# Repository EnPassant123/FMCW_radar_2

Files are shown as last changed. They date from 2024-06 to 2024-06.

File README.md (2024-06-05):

**FMCW Radar Project**

Contains design files, Verilog code for FPGA, and C code for computer.

Can be easily modified to act as a data streaming board (just disable sweep)

Code is still very buggy and does not pass timing. Use at your own risk!

Untested PCB changes: Added LDO to cut down on power supply noise (from USB) more.

The C code is based on libftdi1, and some changes need to be made to ftdi_stream.c

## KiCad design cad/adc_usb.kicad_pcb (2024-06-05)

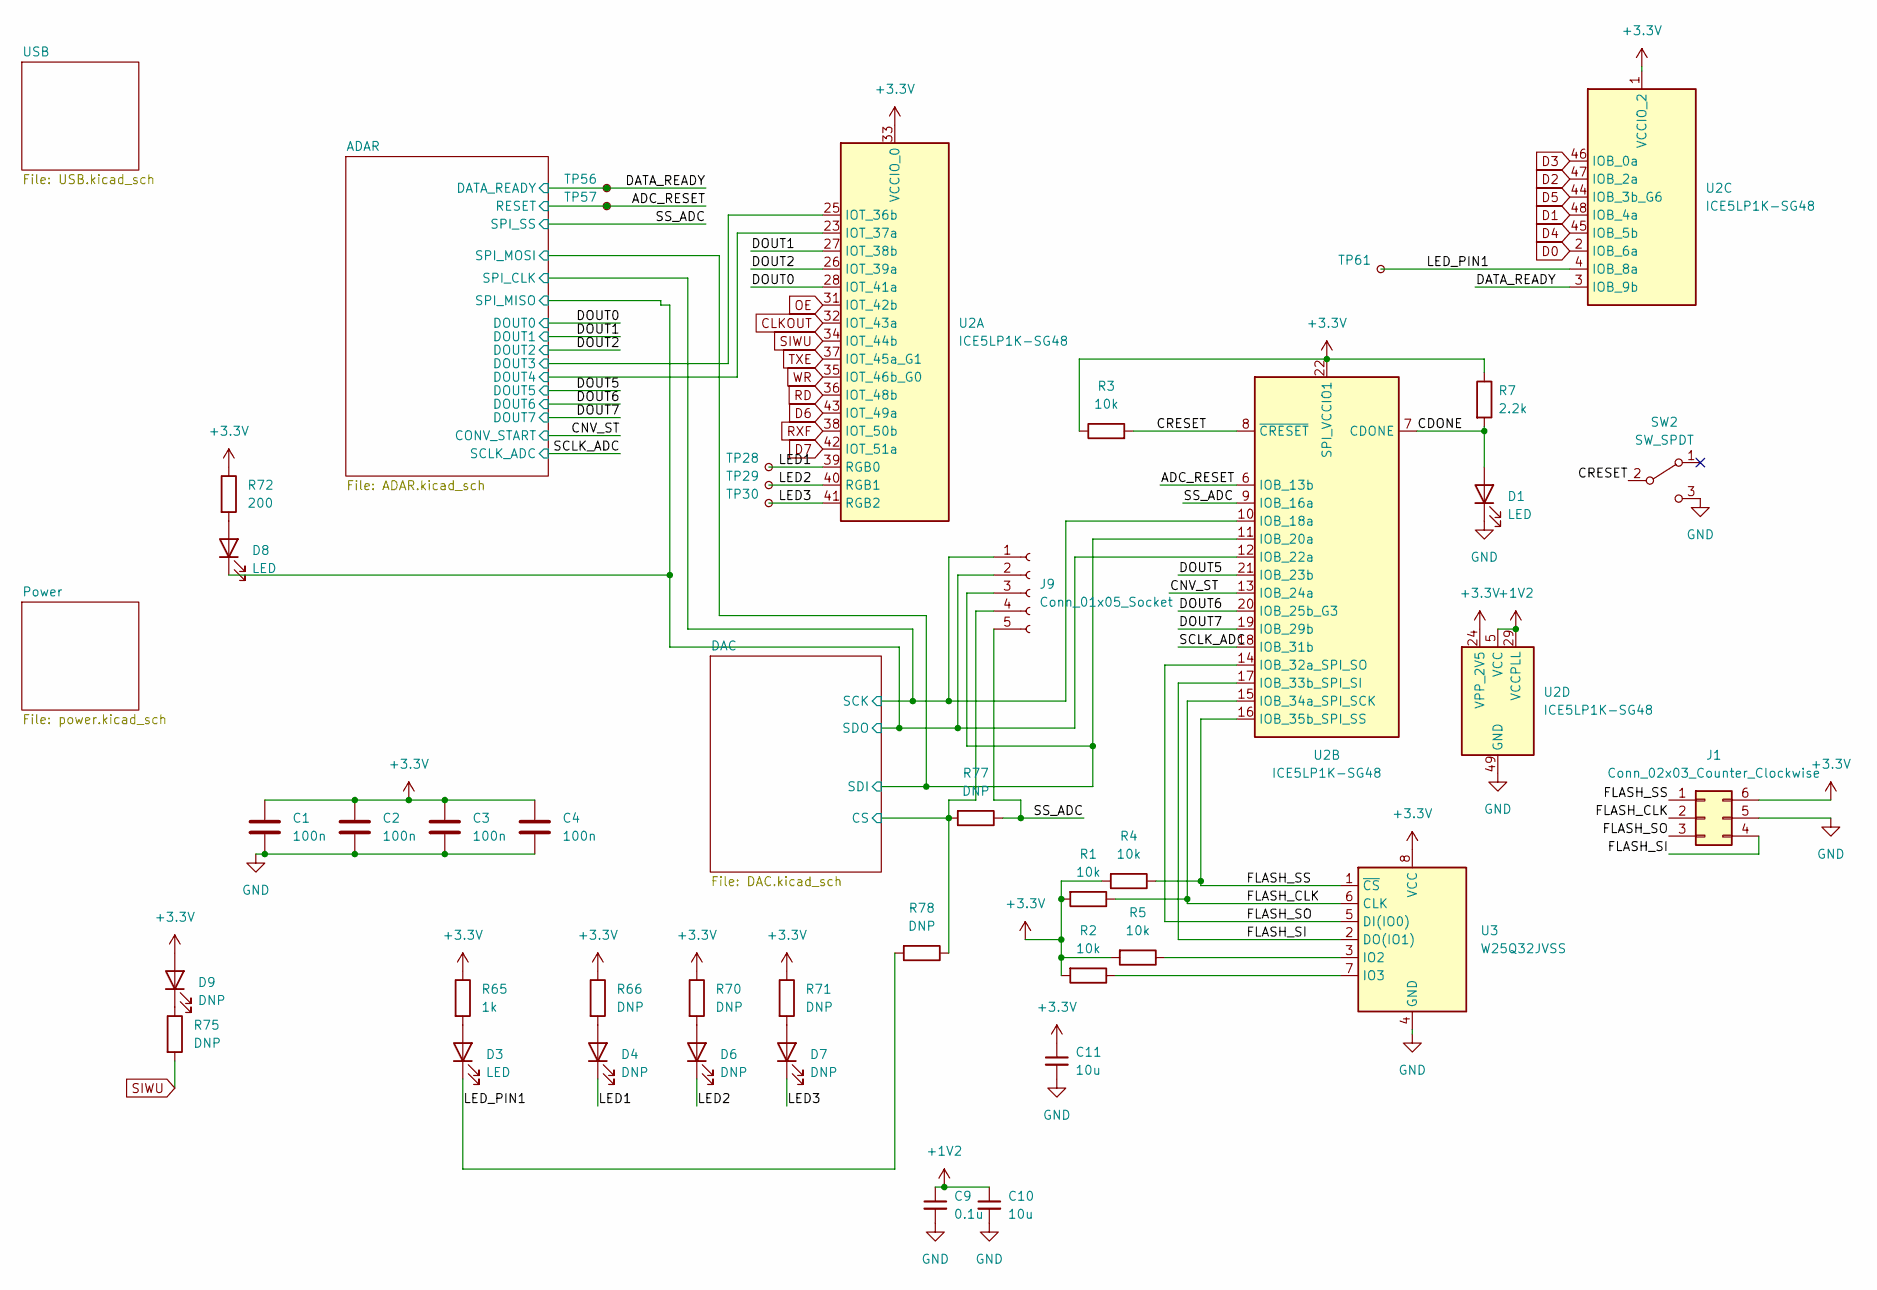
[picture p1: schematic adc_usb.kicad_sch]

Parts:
C1, C2, C3, C4: 100n; C_0603_1608Metric
C9: 0.1u; C_0603_1608Metric
C10, C11: 10u; C_0603_1608Metric
D1, D3, D8: LED; LED_1206_3216Metric
D4, D6, D7, D9: DNP; LED_1206_3216Metric
J1: Conn_02x03_Counter_Clockwise; PinSocket_2x03_P2.54mm_Vertical
J9: Conn_01x05_Socket; PinSocket_1x05_P2.54mm_Vertical
R1, R2, R3, R4, R5: 10k; R_0603_1608Metric
R7: 2.2k; R_0603_1608Metric
R65: 1k; R_0603_1608Metric
R66, R70, R71, R75, R77, R78: DNP; R_0603_1608Metric
R72: 200; R_0603_1608Metric
SW2: SW_SPDT; PinHeader_1x03_P2.54mm_Vertical
TP28, TP29, TP30, TP56, TP57, TP61: TestPoint_Small; TestPoint_Pad_1.0x1.0mm
U2: ICE5LP1K-SG48; QFN-48-1EP_7x7mm_P0.5mm_EP5.6x5.6mm
U3: W25Q32JVSS; SOIC-8_5.23x5.23mm_P1.27mm

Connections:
+1V2: C9.1, C10.1, U2.5 (VCC), U2.29 (VCCPLL), U2.30 (VCC); also elsewhere on the board
+3.3V: C1.1, C2.1, C3.1, C4.1, C11.1, D9.2 (A), J1.6, R1.2, R2.2, R3.1, R4.2, R5.2, R7.1, R65.1, R66.1, R70.1, R71.1, R72.1, U2.1 (VCCIO_2), U2.22 (SPI_VCCIO1), U2.24 (VPP_2V5), U2.33 (VCCIO_0), U3.8 (VCC); also elsewhere on the board
/ADAR/DOUT3: U2.25 (IOT_36b); also elsewhere on the board
/ADAR/DOUT4: U2.23 (IOT_37a); also elsewhere on the board
/ADAR/SPI_CLK: J9.1, U2.10 (IOB_18a); also elsewhere on the board
/ADAR/SPI_MISO: D8.1 (K), J9.2, U2.12 (IOB_22a); also elsewhere on the board
/ADAR/SPI_MOSI: J9.3, U2.11 (IOB_20a); also elsewhere on the board
/ADC_RESET: TP57.1, U2.6 (IOB_13b); also elsewhere on the board
/CDONE: D1.2 (A), R7.2, U2.7 (CDONE)
/CNV_ST: U2.13 (IOB_24a); also elsewhere on the board
/CRESET: R3.2, SW2.2 (B), U2.8 (~CRESET)
/DAC/CS: J9.4, R77.2, R78.1; also elsewhere on the board
/DATA_READY: TP56.1, U2.3 (IOB_9b); also elsewhere on the board
/DOUT0: U2.28 (IOT_41a); also elsewhere on the board
/DOUT1: U2.27 (IOT_38b); also elsewhere on the board
/DOUT2: U2.26 (IOT_39a); also elsewhere on the board
/DOUT5: U2.21 (IOB_23b); also elsewhere on the board
/DOUT6: U2.20 (IOB_25b_G3); also elsewhere on the board
/DOUT7: U2.19 (IOB_29b); also elsewhere on the board
/FLASH_CLK: J1.2, R1.1, U2.15 (IOB_34a_SPI_SCK), U3.6 (CLK)
/FLASH_SI: J1.4, U2.17 (IOB_33b_SPI_SI), U3.2 (DO(IO1))
/FLASH_SO: J1.3, U2.14 (IOB_32a_SPI_SO), U3.5 (DI(IO0))
/FLASH_SS: J1.1, R4.1, U2.16 (IOB_35b_SPI_SS), U3.1 (~CS)
/LED1: D4.1 (K), TP28.1, U2.39 (RGB0)
/LED2: D6.1 (K), TP29.1, U2.40 (RGB1)
/LED3: D7.1 (K), TP30.1, U2.41 (RGB2)
/LED_PIN1: D3.1 (K), R78.2, TP61.1, U2.4 (IOB_8a)
/SCLK_ADC: U2.18 (IOB_31b); also elsewhere on the board
/SS_ADC: J9.5, R77.1, U2.9 (IOB_16a); also elsewhere on the board
CLKOUT: U2.32 (IOT_43a); also elsewhere on the board
D0: U2.2 (IOB_6a); also elsewhere on the board
D1: U2.48 (IOB_4a); also elsewhere on the board
D2: U2.47 (IOB_2a); also elsewhere on the board
D3: U2.46 (IOB_0a); also elsewhere on the board
D4: U2.45 (IOB_5b); also elsewhere on the board
D5: U2.44 (IOB_3b_G6); also elsewhere on the board
D6: U2.43 (IOT_49a); also elsewhere on the board
D7: U2.42 (IOT_51a); also elsewhere on the board
GND: C1.2, C2.2, C3.2, C4.2, C9.2, C10.2, C11.2, D1.1 (K), J1.5, SW2.3 (C), U2.49 (GND), U3.4 (GND); also elsewhere on the board
unnamed: D3.2 (A), R65.2
unnamed: D4.2 (A), R66.2
unnamed: D6.2 (A), R70.2
unnamed: D7.2 (A), R71.2
unnamed: D8.2 (A), R72.2
unnamed: D9.1 (K), R75.1
unnamed: R5.1, U3.3 (IO2)
unnamed: R2.1, U3.7 (IO3)
OE: U2.31 (IOT_42b); also elsewhere on the board
RD: U2.36 (IOT_48b); also elsewhere on the board
RXF: U2.38 (IOT_50b); also elsewhere on the board
SIWU: R75.2, U2.34 (IOT_44b); also elsewhere on the board
TXE: U2.37 (IOT_45a_G1); also elsewhere on the board
WR: U2.35 (IOT_46b_G0); also elsewhere on the board

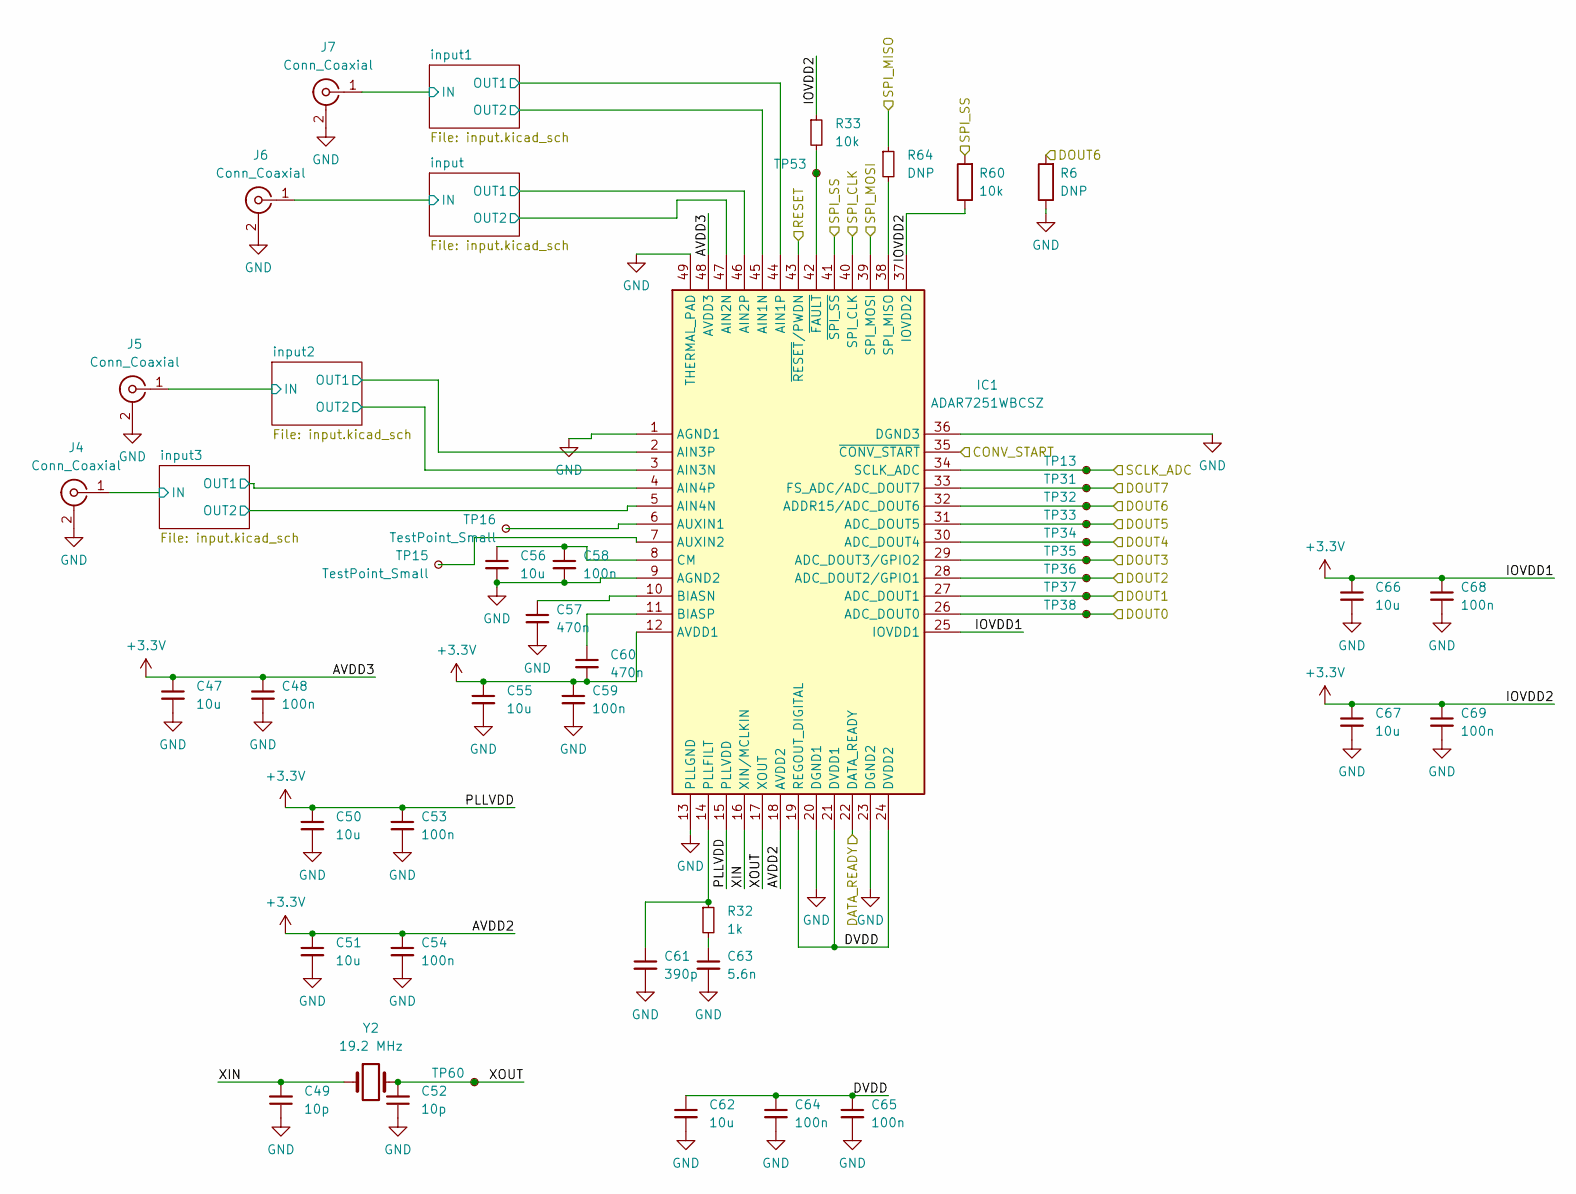
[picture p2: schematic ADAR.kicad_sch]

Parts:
C47, C50, C51, C55, C56, C62, C66, C67: 10u; C_0603_1608Metric
C48, C53, C54, C58, C59, C64, C65, C68, C69: 100n; C_0603_1608Metric
C49, C52: 10p; C_0603_1608Metric
C57, C60: 470n; C_0603_1608Metric
C61: 390p; C_0603_1608Metric
C63: 5.6n; C_0603_1608Metric
IC1: ADAR7251WBCSZ; LFCSP-48-1EP_7x7mm_P0.5mm_EP4.1x4.1mm; Manufacturer_Part_Number ADAR7251WBCSZ; Mouser Part Number 584-ADAR7251WBCSZ
J4, J5, J6, J7: Conn_Coaxial; SMA_Samtec_SMA-J-P-X-ST-EM1_EdgeMount
R6, R64: DNP; R_0603_1608Metric
R32: 1k; R_0603_1608Metric
R33, R60: 10k; R_0603_1608Metric
TP13, TP31, TP32, TP33, TP34, TP35, TP36, TP37, TP38, TP53: TestPoint_Small; TestPoint_Pad_1.0x1.0mm
TP15, TP16, TP60: TestPoint_Small; TestPoint_Pad_2.0x2.0mm
Y2: 19.2 MHz; Crystal_SMD_3225-4Pin_3.2x2.5mm

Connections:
+3.3V: C47.1, C48.1, C50.1, C51.1, C53.1, C54.1, C55.1, C59.1, C60.2, C66.1, C67.1, C68.1, C69.1, IC1.12 (AVDD1), IC1.15 (PLLVDD), IC1.18 (AVDD2), IC1.25 (IOVDD1), IC1.37 (IOVDD2), IC1.48 (AVDD3), R33.1, R60.1; also elsewhere on the board
/ADAR/DOUT3: IC1.29 (ADC_DOUT3/GPIO2), TP35.1; also elsewhere on the board
/ADAR/DOUT4: IC1.30 (ADC_DOUT4), TP34.1; also elsewhere on the board
/ADAR/DVDD: C62.1, C64.1, C65.1, IC1.19 (REGOUT_DIGITAL), IC1.21 (DVDD1), IC1.24 (DVDD2)
/ADAR/SPI_CLK: IC1.40 (SPI_CLK); also elsewhere on the board
/ADAR/SPI_MISO: R64.1; also elsewhere on the board
/ADAR/SPI_MOSI: IC1.39 (SPI_MOSI); also elsewhere on the board
/ADAR/XIN: C49.2, IC1.16 (XIN/MCLKIN), Y2.1
/ADAR/XOUT: C52.2, IC1.17 (XOUT), TP60.1, Y2.2
/ADAR/input1/OUT1: IC1.44 (AIN1P); also elsewhere on the board
/ADAR/input1/OUT2: IC1.45 (AIN1N); also elsewhere on the board
/ADAR/input2/IN: J5.1 (In); also elsewhere on the board
/ADAR/input2/OUT1: IC1.2 (AIN3P); also elsewhere on the board
/ADAR/input2/OUT2: IC1.3 (AIN3N); also elsewhere on the board
/ADAR/input3/OUT1: IC1.4 (AIN4P); also elsewhere on the board
/ADAR/input3/OUT2: IC1.5 (AIN4N); also elsewhere on the board
/ADAR/input/OUT1: IC1.46 (AIN2P); also elsewhere on the board
/ADAR/input/OUT2: IC1.47 (AIN2N); also elsewhere on the board
/ADC_RESET: IC1.43 (~RESET/PWDN); also elsewhere on the board
/CNV_ST: IC1.35 (~CONV_START); also elsewhere on the board
/DATA_READY: IC1.22 (DATA_READY); also elsewhere on the board
/DOUT0: IC1.26 (ADC_DOUT0), TP38.1; also elsewhere on the board
/DOUT1: IC1.27 (ADC_DOUT1), TP37.1; also elsewhere on the board
/DOUT2: IC1.28 (ADC_DOUT2/GPIO1), TP36.1; also elsewhere on the board
/DOUT5: IC1.31 (ADC_DOUT5), TP33.1; also elsewhere on the board
/DOUT6: IC1.32 (ADDR15/ADC_DOUT6), R6.2, TP32.1; also elsewhere on the board
/DOUT7: IC1.33 (FS_ADC/ADC_DOUT7), TP31.1; also elsewhere on the board
/SCLK_ADC: IC1.34 (SCLK_ADC), TP13.1; also elsewhere on the board
/SS_ADC: IC1.41 (~SPI_SS), R60.2; also elsewhere on the board
GND: C47.2, C48.2, C49.1, C50.2, C51.2, C52.1, C53.2, C54.2, C55.2, C56.2, C57.2, C58.2, C59.2, C61.2, C62.2, C63.2, C64.2, C65.2, C66.2, C67.2, C68.2, C69.2, IC1.1 (AGND1), IC1.9 (AGND2), IC1.13 (PLLGND), IC1.20 (DGND1), IC1.23 (DGND2), IC1.36 (DGND3), IC1.49 (THERMAL_PAD), J4.2 (Ext), J5.2 (Ext), J6.2 (Ext), J7.2 (Ext), R6.1; also elsewhere on the board
unnamed: C63.1, R32.2
unnamed: IC1.6 (AUXIN1), TP16.1
unnamed: IC1.7 (AUXIN2), TP15.1
unnamed: C57.1, IC1.10 (BIASN)
unnamed: C60.1, IC1.11 (BIASP)
unnamed: C56.1, C58.1, IC1.8 (CM)
unnamed: C61.1, IC1.14 (PLLFILT), R32.1
unnamed: IC1.38 (SPI_MISO), R64.2
unnamed: IC1.42 (~FAULT), R33.2, TP53.1

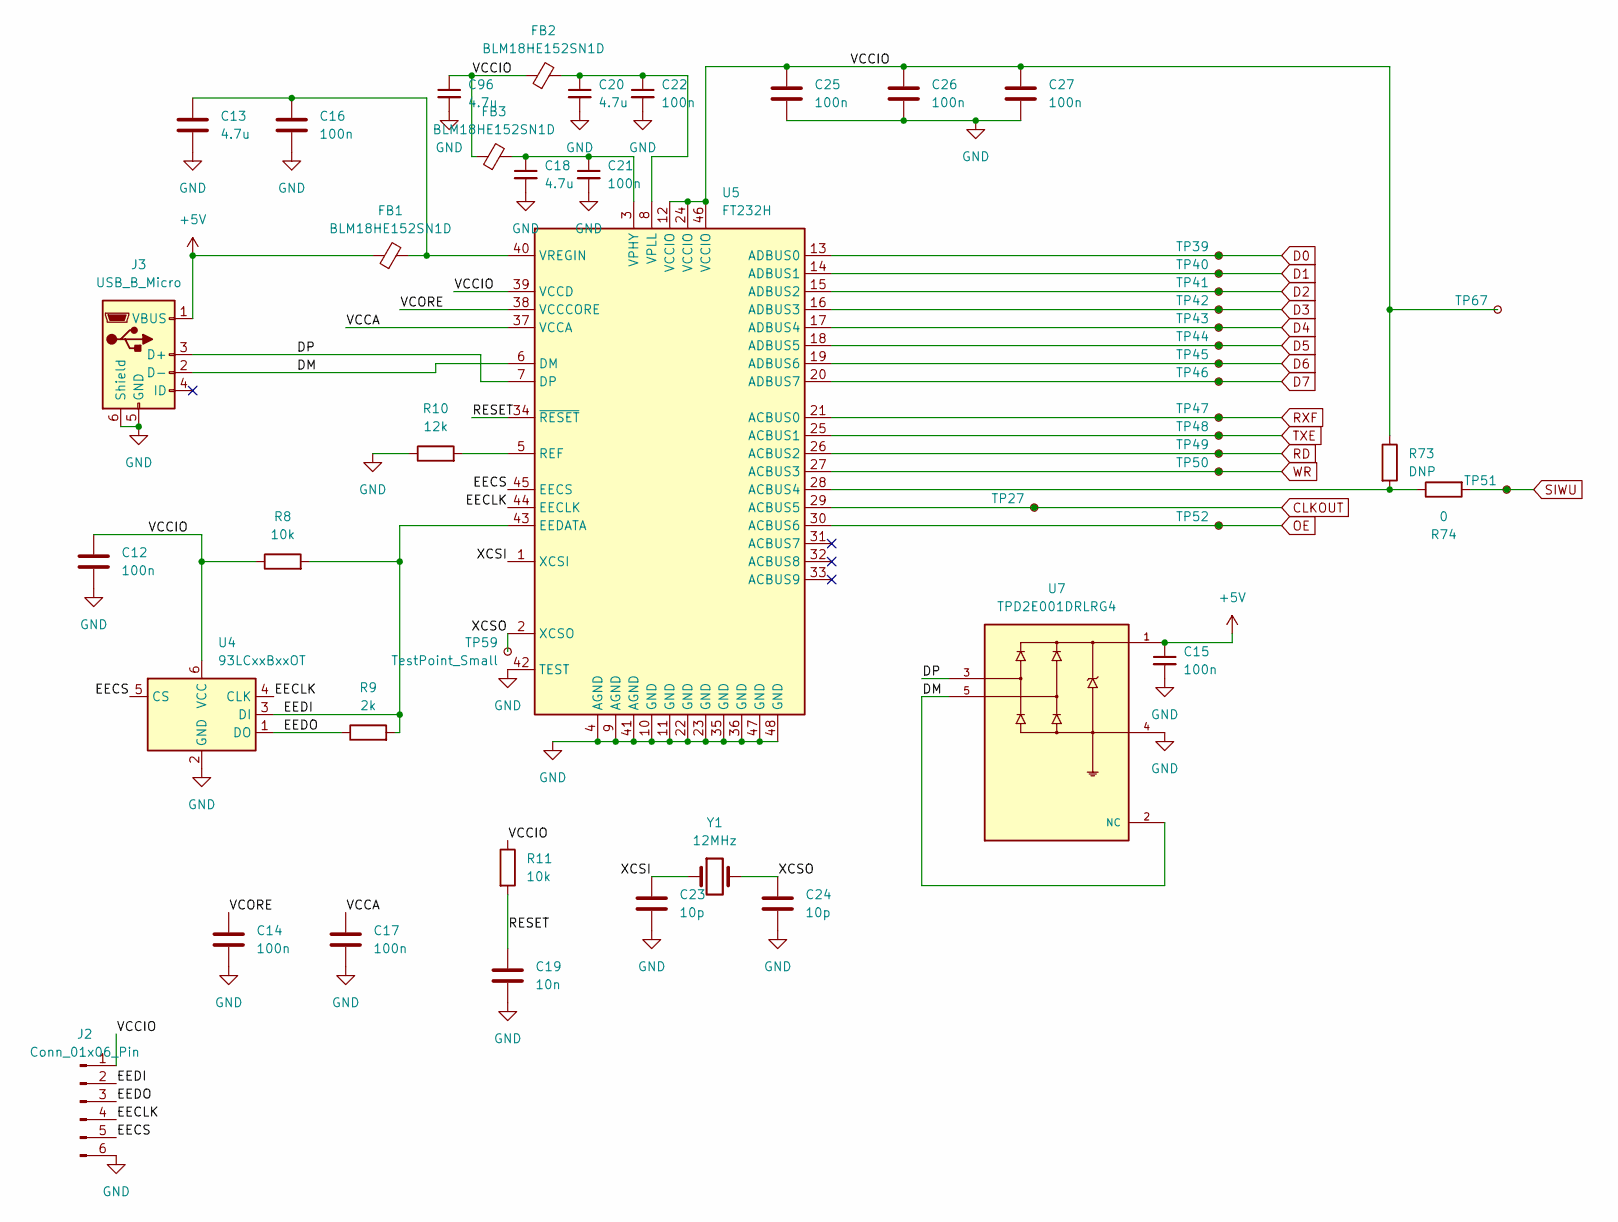
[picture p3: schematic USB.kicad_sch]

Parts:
C12, C14, C15, C16, C17, C21, C22, C25, C26, C27: 100n; C_0603_1608Metric
C13, C18, C20, C96: 4.7u; C_0603_1608Metric
C19: 10n; C_0603_1608Metric
C23, C24: 10p; C_0603_1608Metric
FB1, FB2, FB3: BLM18HE152SN1D; L_0603_1608Metric
J2: Conn_01x06_Pin; PinSocket_1x06_P2.54mm_Vertical
J3: USB_B_Micro; USB_Micro-B_Amphenol_10118193-0001LF_Horizontal
R8, R11: 10k; R_0603_1608Metric
R9: 2k; R_0603_1608Metric
R10: 12k; R_0603_1608Metric
R73: DNP; R_0603_1608Metric
R74: 0; R_0603_1608Metric
TP27, TP39, TP40, TP41, TP42, TP43, TP44, TP45, TP46, TP47, TP48, TP49, TP50, TP51, TP52, TP67: TestPoint_Small; TestPoint_Pad_1.0x1.0mm
TP59: TestPoint_Small; TestPoint_Pad_2.0x2.0mm
U4: 93LCxxBxxOT; SOT-23-6
U5: FT232H; LQFP-48_7x7mm_P0.5mm
U7: TPD2E001DRLRG4; SOT-553; PARTREV I
Y1: 12MHz; Crystal_SMD_3225-4Pin_3.2x2.5mm

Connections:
+5V: C15.1, FB1.1, J3.1 (VBUS), U7.1; also elsewhere on the board
/USB/DM: J3.2 (D-), U5.6 (DM), U7.2 (NC), U7.5
/USB/DP: J3.3 (D+), U5.7 (DP), U7.3
/USB/EECLK: J2.4, U4.4 (CLK), U5.44 (EECLK)
/USB/EECS: J2.5, U4.5 (CS), U5.45 (EECS)
/USB/EEDI: J2.2, R8.2, R9.2, U4.3 (DI), U5.43 (EEDATA)
/USB/EEDO: J2.3, R9.1, U4.1 (DO)
/USB/RESET: C19.1, R11.2, U5.34 (~RESET)
/USB/VCCA: C17.1, U5.37 (VCCA)
/USB/VCCIO: C12.1, C25.1, C26.1, C27.1, C96.1, FB2.1, FB3.1, J2.1, R8.1, R11.1, R73.1, TP67.1, U4.6 (VCC), U5.12 (VCCIO), U5.24 (VCCIO), U5.39 (VCCD), U5.46 (VCCIO)
/USB/VCORE: C14.1, U5.38 (VCCCORE)
/USB/XCSI: C23.1, U5.1 (XCSI), Y1.1
/USB/XCSO: C24.1, TP59.1, U5.2 (XCSO), Y1.2
CLKOUT: TP27.1, U5.29 (ACBUS5); also elsewhere on the board
D0: TP39.1, U5.13 (ADBUS0); also elsewhere on the board
D1: TP40.1, U5.14 (ADBUS1); also elsewhere on the board
D2: TP41.1, U5.15 (ADBUS2); also elsewhere on the board
D3: TP42.1, U5.16 (ADBUS3); also elsewhere on the board
D4: TP43.1, U5.17 (ADBUS4); also elsewhere on the board
D5: TP44.1, U5.18 (ADBUS5); also elsewhere on the board
D6: TP45.1, U5.19 (ADBUS6); also elsewhere on the board
D7: TP46.1, U5.20 (ADBUS7); also elsewhere on the board
GND: C12.2, C13.2, C14.2, C15.2, C16.2, C17.2, C18.2, C19.2, C20.2, C21.2, C22.2, C23.2, C24.2, C25.2, C26.2, C27.2, C96.2, J2.6, J3.5 (GND), J3.6 (Shield), R10.1, U4.2 (GND), U5.4 (AGND), U5.9 (AGND), U5.10 (GND), U5.11 (GND), U5.22 (GND), U5.23 (GND), U5.35 (GND), U5.36 (GND), U5.41 (AGND), U5.42 (TEST), U5.47 (GND), U5.48 (GND), U7.4; also elsewhere on the board
unnamed: R73.2, R74.1, U5.28 (ACBUS4)
unnamed: R10.2, U5.5 (REF)
unnamed: C18.1, C21.1, FB3.2, U5.3 (VPHY)
unnamed: C20.1, C22.1, FB2.2, U5.8 (VPLL)
unnamed: C13.1, C16.1, FB1.2, U5.40 (VREGIN)
OE: TP52.1, U5.30 (ACBUS6); also elsewhere on the board
RD: TP49.1, U5.26 (ACBUS2); also elsewhere on the board
RXF: TP47.1, U5.21 (ACBUS0); also elsewhere on the board
SIWU: R74.2, TP51.1; also elsewhere on the board
TXE: TP48.1, U5.25 (ACBUS1); also elsewhere on the board
WR: TP50.1, U5.27 (ACBUS3); also elsewhere on the board

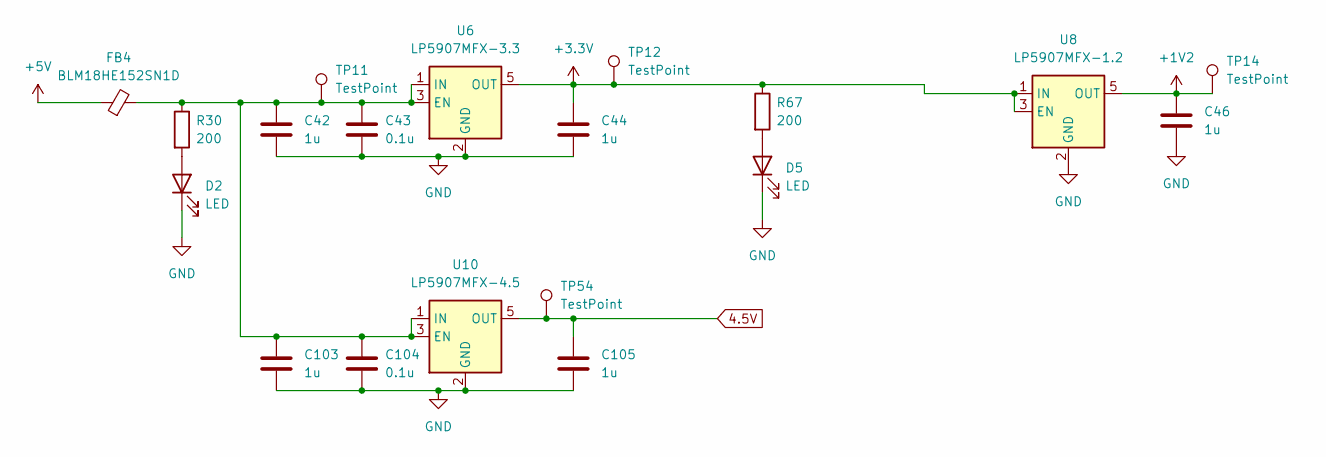
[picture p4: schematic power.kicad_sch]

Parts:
C42, C44, C46, C103, C105: 1u; C_0603_1608Metric
C43, C104: 0.1u; C_0603_1608Metric
D2, D5: LED; LED_1206_3216Metric
FB4: BLM18HE152SN1D; L_0603_1608Metric
R30, R67: 200; R_0603_1608Metric
TP11, TP12, TP14, TP54: TestPoint; TestPoint_Pad_2.0x2.0mm
U6: LP5907MFX-3.3; SOT-23-5
U8: LP5907MFX-1.2; SOT-23-5
U10: LP5907MFX-4.5; SOT-23-5

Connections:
4.5V: C105.1, TP54.1, U10.5 (OUT); also elsewhere on the board
+1V2: C46.1, TP14.1, U8.5 (OUT); also elsewhere on the board
+3.3V: C44.1, R67.1, TP12.1, U6.5 (OUT), U8.1 (IN), U8.3 (EN); also elsewhere on the board
+5V: FB4.1; also elsewhere on the board
GND: C42.2, C43.2, C44.2, C46.2, C103.2, C104.2, C105.2, D2.1 (K), D5.1 (K), U6.2 (GND), U8.2 (GND), U10.2 (GND); also elsewhere on the board
unnamed: D2.2 (A), R30.2
unnamed: D5.2 (A), R67.2
unnamed: C42.1, C43.1, C103.1, C104.1, FB4.2, R30.1, TP11.1, U6.1 (IN), U6.3 (EN), U10.1 (IN), U10.3 (EN)

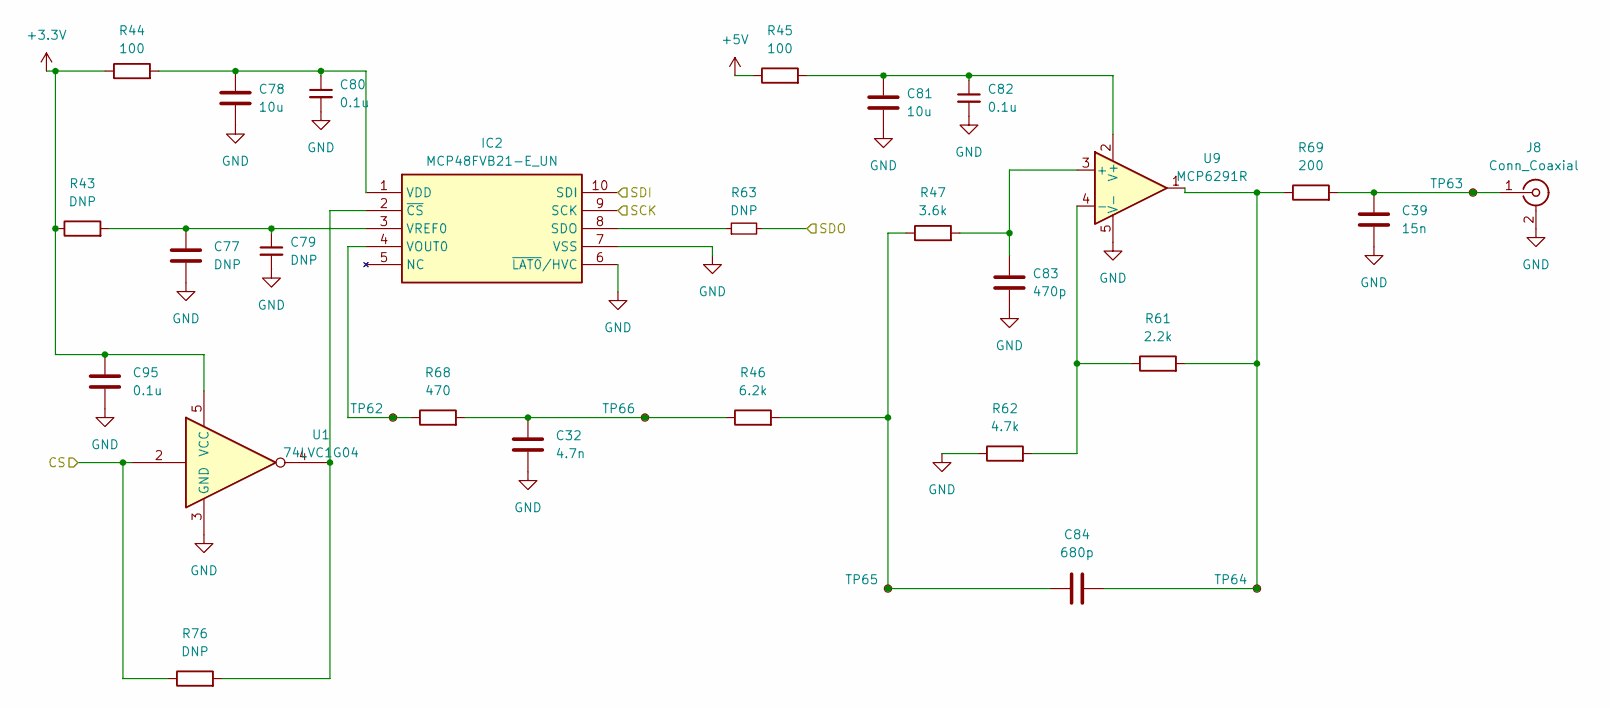
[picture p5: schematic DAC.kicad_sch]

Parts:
C32: 4.7n; C_0603_1608Metric
C39: 15n; C_0603_1608Metric
C77, C79: DNP; C_0603_1608Metric
C78, C81: 10u; C_0603_1608Metric
C80, C82, C95: 0.1u; C_0603_1608Metric
C83: 470p; C_0603_1608Metric
C84: 680p; C_0603_1608Metric
IC2: MCP48FVB21-E_UN; MSOP-10_3x3mm_P0.5mm; Manufacturer_Part_Number MCP48FVB21-E/UN; Mouser Part Number 579-MCP48FVB21-E/UN
J8: Conn_Coaxial; SMA_Samtec_SMA-J-P-X-ST-EM1_EdgeMount
R43, R63, R76: DNP; R_0603_1608Metric
R44, R45: 100; R_0603_1608Metric
R46: 6.2k; R_0603_1608Metric
R47: 3.6k; R_0603_1608Metric
R61: 2.2k; R_0603_1608Metric
R62: 4.7k; R_0603_1608Metric
R68: 470; R_0603_1608Metric
R69: 200; R_0603_1608Metric
TP62, TP63, TP64, TP65, TP66: TestPoint_Small; TestPoint_Pad_1.0x1.0mm
U1: 74LVC1G04; SOT-353_SC-70-5
U9: MCP6291R; SOT-23-5

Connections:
+3.3V: C95.1, R43.1, R44.1, U1.5 (VCC); also elsewhere on the board
+5V: R45.1; also elsewhere on the board
/ADAR/SPI_CLK: IC2.9 (SCK); also elsewhere on the board
/ADAR/SPI_MISO: R63.2; also elsewhere on the board
/ADAR/SPI_MOSI: IC2.10 (SDI); also elsewhere on the board
/DAC/CS: R76.1, U1.2; also elsewhere on the board
GND: C32.2, C39.2, C77.2, C78.2, C79.2, C80.2, C81.2, C82.2, C83.2, C95.2, IC2.6 (~LAT0/HVC), IC2.7 (VSS), J8.2 (Ext), R62.1, U1.3 (GND), U9.5 (V-); also elsewhere on the board
unnamed: C32.1, R46.1, R68.2, TP66.1
unnamed: C84.1, R46.2, R47.1, TP65.1
unnamed: C84.2, R61.2, R69.1, TP64.1, U9.1
unnamed: IC2.8 (SDO), R63.1
unnamed: C78.1, C80.1, IC2.1 (VDD), R44.2
unnamed: IC2.4 (VOUT0), R68.1, TP62.1
unnamed: C77.1, C79.1, IC2.3 (VREF0), R43.2
unnamed: IC2.2 (~CS), R76.2, U1.4
unnamed: C39.1, J8.1 (In), R69.2, TP63.1
unnamed: C83.1, R47.2, U9.3 (+)
unnamed: R61.1, R62.2, U9.4 (-)
unnamed: C81.1, C82.1, R45.2, U9.2 (V+)

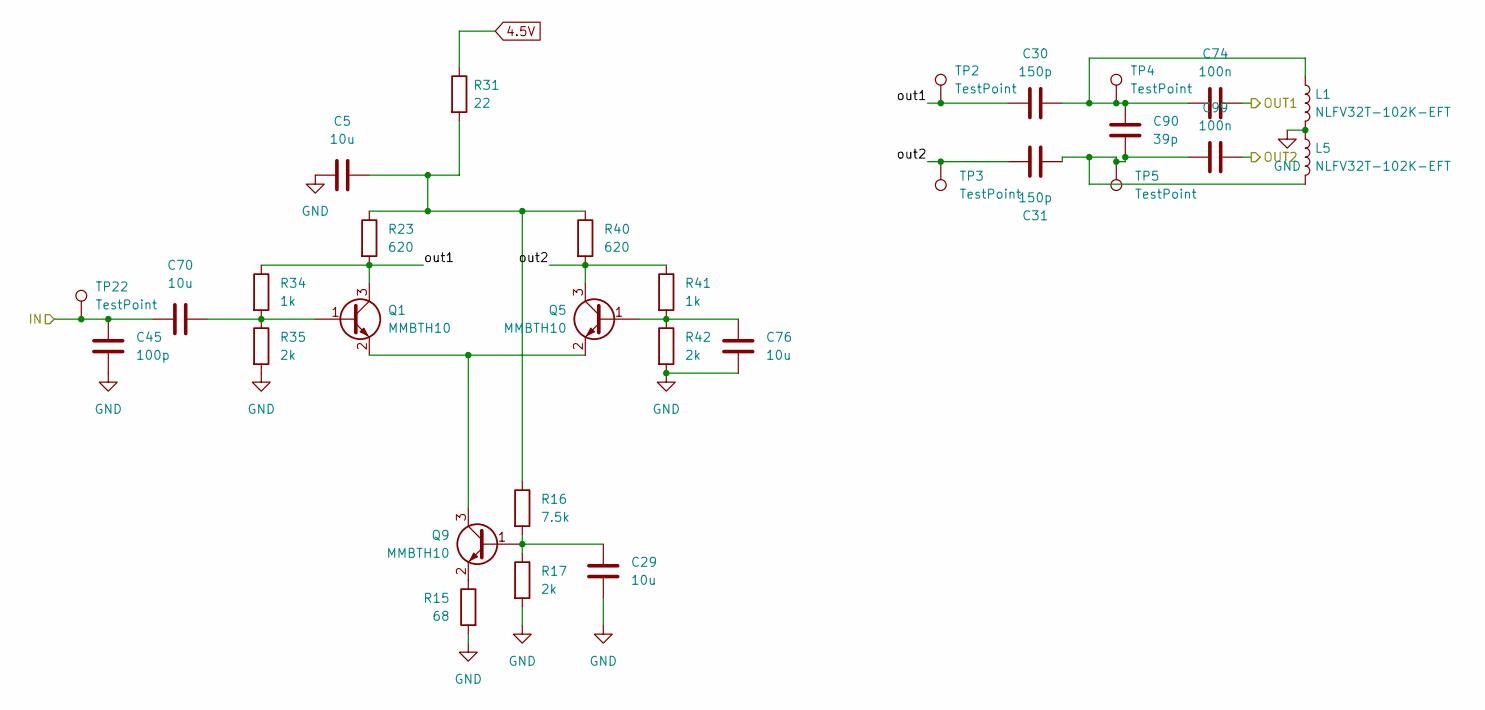
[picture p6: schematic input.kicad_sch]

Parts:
C5, C29, C70, C76: 10u; C_0603_1608Metric
C30, C31: 150p; C_0603_1608Metric
C45: 100p; C_0603_1608Metric
C74, C99: 100n; C_0603_1608Metric
C90: 39p; C_0603_1608Metric
L1, L5: NLFV32T-102K-EFT; L_1210_3225Metric
Q1, Q5, Q9: MMBTH10; SOT-23-3
R15: 68; R_0603_1608Metric
R16: 7.5k; R_0603_1608Metric
R17, R35, R42: 2k; R_0603_1608Metric
R23, R40: 620; R_0603_1608Metric
R31: 22; R_0603_1608Metric
R34, R41: 1k; R_0603_1608Metric
TP2, TP3, TP4, TP5, TP22: TestPoint; TestPoint_Pad_1.0x1.0mm

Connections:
4.5V: R31.1; also elsewhere on the board
/ADAR/input1/OUT1: C74.2; also elsewhere on the board
/ADAR/input1/OUT2: C99.2; also elsewhere on the board
GND: C5.1, C29.2, C45.1, C76.2, L1.2, L5.1, R15.2, R17.2, R35.2, R42.2; also elsewhere on the board
unnamed: Q1.2 (E), Q5.2 (E), Q9.3 (C)
unnamed: C29.1, Q9.1 (B), R16.2, R17.1
unnamed: Q9.2 (E), R15.1

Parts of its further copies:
C6, C7, C8, C28, C34, C35, C36, C41, C71, C85, C86, C91: 10u; C_0603_1608Metric
C33, C40, C75: 39p; C_0603_1608Metric
C37, C38, C72, C73, C87, C88: 150p; C_0603_1608Metric
C89, C97, C98, C100, C101, C102: 100n; C_0603_1608Metric
C92, C93, C94: 100p; C_0603_1608Metric
L2, L3, L4, L6, L7, L8: NLFV32T-102K-EFT; L_1210_3225Metric
Q2, Q3, Q4, Q6, Q7, Q8, Q10, Q11, Q12: MMBTH10; SOT-23-3
R12, R19, R21, R28, R48, R55: 1k; R_0603_1608Metric
R13, R20, R22, R26, R29, R39, R49, R53, R56: 2k; R_0603_1608Metric
R14, R18, R27, R36, R50, R54: 620; R_0603_1608Metric
R24, R37, R51: 68; R_0603_1608Metric
R25, R38, R52: 7.5k; R_0603_1608Metric
R57, R58, R59: 22; R_0603_1608Metric
TP1, TP6, TP7, TP8, TP9, TP10, TP17, TP18, TP19, TP20, TP21, TP23, TP24, TP25, TP26: TestPoint; TestPoint_Pad_1.0x1.0mm

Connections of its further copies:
4.5V: R57.1, R58.1, R59.1; also elsewhere on the board
/ADAR/input2/IN: C35.1, C92.2, TP6.1; also elsewhere on the board
/ADAR/input2/OUT1: C89.2; also elsewhere on the board
/ADAR/input2/OUT2: C100.2; also elsewhere on the board
/ADAR/input2/out2: C38.1, Q6.3 (C), R27.2, R28.1, TP8.1
/ADAR/input3/OUT1: C98.2; also elsewhere on the board
/ADAR/input3/OUT2: C102.2; also elsewhere on the board
/ADAR/input3/out1: C87.1, Q4.3 (C), R48.1, R50.2, TP23.1
/ADAR/input3/out2: C88.1, Q8.3 (C), R54.2, R55.1, TP24.1
/ADAR/input/OUT1: C97.2; also elsewhere on the board
/ADAR/input/OUT2: C101.2; also elsewhere on the board
GND: C6.1, C7.1, C8.1, C34.2, C36.2, C41.2, C71.2, C86.2, C91.2, C92.1, C93.1, C94.1, L2.2, L3.2, L4.2, L6.1, L7.1, L8.1, R13.2, R20.2, R22.2, R24.2, R26.2, R29.2, R37.2, R39.2, R49.2, R51.2, R53.2, R56.2; also elsewhere on the board
unnamed: C8.2, R50.1, R52.1, R54.1, R59.2
unnamed: C37.2, C40.1, C89.1, L2.1, TP9.1
unnamed: C72.2, C75.1, C97.1, L3.1, TP20.1
unnamed: C38.2, C40.2, C100.1, L6.2, TP10.1
unnamed: C73.2, C75.2, C101.1, L7.2, TP21.1
unnamed: C35.2, Q2.1 (B), R21.2, R22.1
unnamed: C85.2, Q4.1 (B), R48.2, R49.1
unnamed: C41.1, Q6.1 (B), R28.2, R29.1
unnamed: C91.1, Q8.1 (B), R55.2, R56.1
unnamed: C36.1, Q10.1 (B), R25.2, R26.1
unnamed: Q2.2 (E), Q6.2 (E), Q10.3 (C)
unnamed: Q10.2 (E), R24.1
unnamed: C71.1, Q11.1 (B), R38.2, R39.1
unnamed: Q3.2 (E), Q7.2 (E), Q11.3 (C)
unnamed: Q11.2 (E), R37.1
unnamed: C86.1, Q12.1 (B), R52.2, R53.1
unnamed: Q4.2 (E), Q8.2 (E), Q12.3 (C)
unnamed: Q12.2 (E), R51.1

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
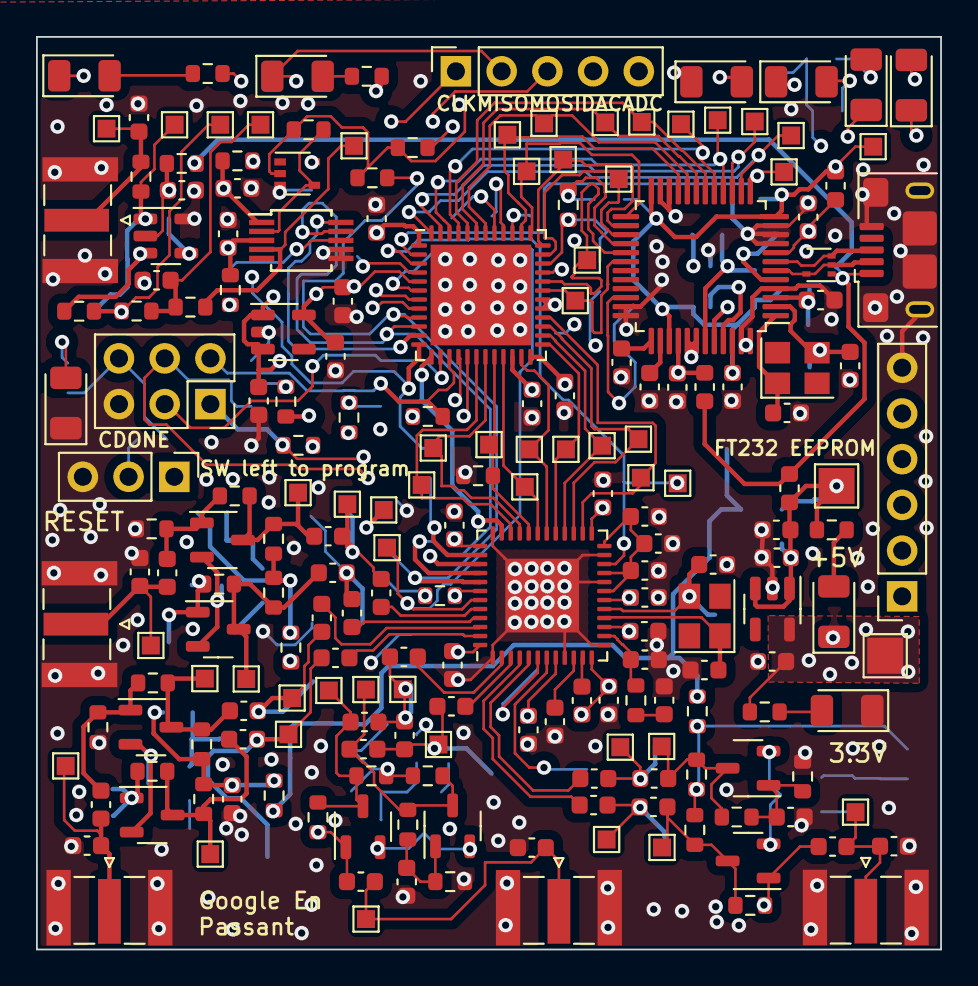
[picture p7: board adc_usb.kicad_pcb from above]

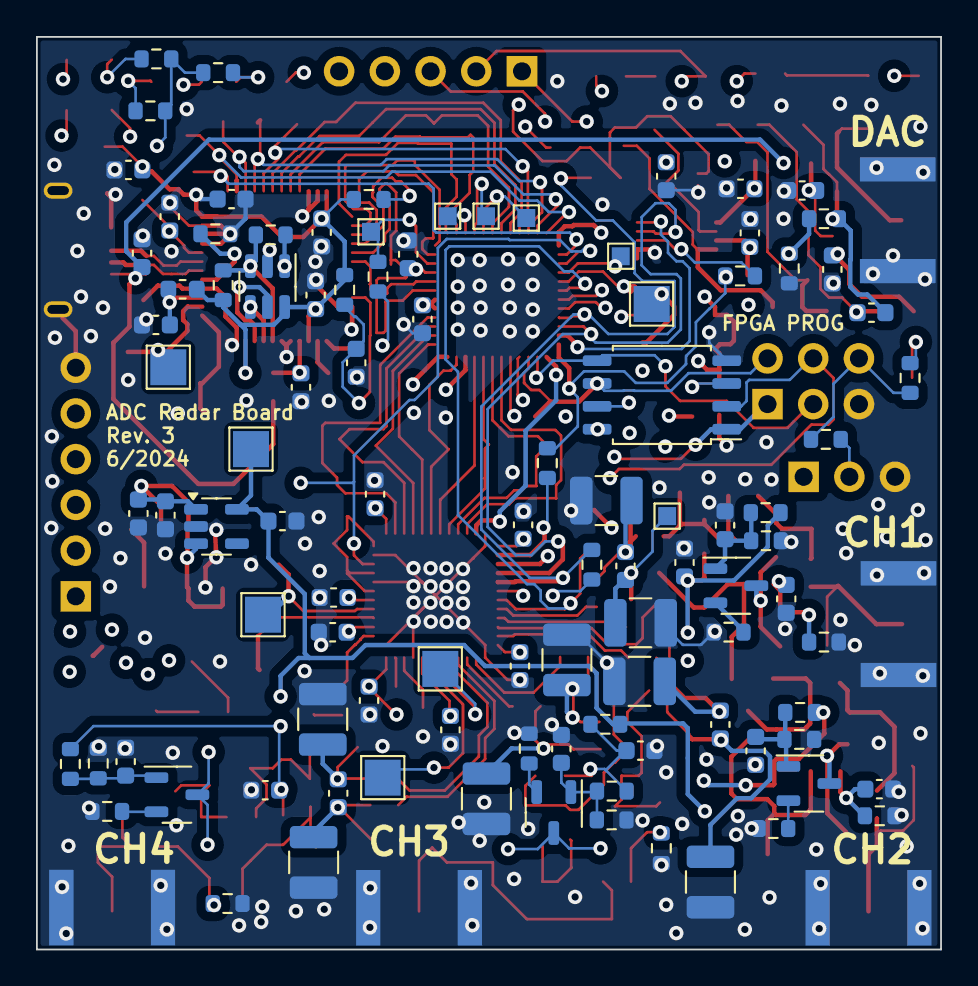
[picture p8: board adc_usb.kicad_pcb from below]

Board: 6 copper layers, 50.2 x 50.7 mm, 305 parts (100 on the bottom side), 151 nets.

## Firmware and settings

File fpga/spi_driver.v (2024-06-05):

//Skip most of ADC initialization if simulating



`ifdef SIMULATION
`include "spi_adc.v"
`include "spi_dac.v"

`define ADC_INIT_COUNT 5
`define PLL_WAIT 100

`else

`define ADC_INIT_COUNT conf_len
`define PLL_WAIT 131071
`endif


module spi_driver (
  //clk: 60MHz - used for ADC
  input clk,
  //clkmult: 57.6 MHz - used for DAC
  input clkmult,
  
  //SPI outputs
  output sclk,  
  output cs,
  output mosi,
  
  //HIGH = run ADC initalization sequence
  //LOW = write 40 bits to ADC
  input init,
  input [39:0] data,
  
  //HIGH = write to ADC  
  input start_adc,
  //HIGH = start sweep
  input start_dac,
  
  //Do not enable ADC/DAC when busy
  output busy,
  
  //Synchronization signal for ADC
  output data_valid,
  
  //Sweep parameters for DAC
  input [31:0] SWEEP_START,
  input [31:0] SWEEP_DIFF,
  input [31:0] SWEEP_STOP
  
);
  
  //ADC configuration: command list
  
  localparam conf_len = 22;
  localparam [40 * conf_len - 1: 0] adc_conf = 
  {40'h0200000000, 40'h0200033001, 40'hffffffffff, 40'hffffffffff,
// 40'h0201021111, 
40'h02010000AA,
  40'h0201C20001, 40'h0201400002,
  40'h0201C10004, 40'h0202840003, 40'h0202860003, 40'h0202880003,
  40'h0202890003, 40'h02028A0003, 40'h02028B0003, 40'h02028C0003,
  40'h02028D0003, 40'h02028E0003, 40'h0202910003, 40'h02030a0001,
  40'h0203080013, 40'h0203010306, 40'h0200400001};
  
  //Keeps track of if we're doing ADC initialization
  reg is_init = 0;

  //Busy signal for both ADC and DAC
  wire busy_dac;
  wire busy_adc;
  
  //Start signal for ADC and DAC driver
  reg dac_start = 0;
  reg adc_start = 0;
  
  wire adc_cs;
  
  //Signal for starting special 56 bit command for turning off CRC
  reg adc_init=0;
  
  //Counter for initalization
  reg [$clog2(conf_len)-1:0] counter=0; 
  
  //Delay (to wait for ADC PLL to lock)
  reg [16:0] delay=0;
  
  
  wire sclk_dac;
  wire mosi_dac;
  
  wire sclk_adc;
  wire mosi_adc;
  
  
  wire [39:0] data_adc;
  
  reg [39:0] data_adc_init =0;
  
  reg [31:0] sweep_count = 0;
  reg [31:0] diff = 0;
  reg [31:0] diff2 = 0;

  
  reg reset_sweep = 0;
  
  wire [23:0] data_dac;
  
  //Switch all outputs
  assign sclk = busy_adc ? sclk_adc : sclk_dac;
  assign mosi = busy_adc ? mosi_adc : mosi_dac;
  assign cs = busy_adc ? adc_cs : 1;
  
  //Switch between initialization data
  assign data_adc = is_init ? data_adc_init : data;
  
  //Data going into DAC (most significant 12 bits of sweep counter)
  assign data_dac = {12'b0, sweep_count[31:20]};
  
  
  assign busy = is_init | busy_dac | busy_adc | reset_sweep | dac_start;
  assign data_valid = (busy_dac | dac_start | reset_sweep);
  wire load_data_dac;

  
  spi_dac SPI_DAC(
    .o_busy(busy_dac),
    .start(dac_start),
    .o_sclk(sclk_dac),
    .o_mosi(mosi_dac),
    .data(data_dac),
    .clk(clkmult),
    .load_data_o(load_data_dac)
  );
  
  spi_adc SPI_ADC (
    .o_busy(busy_adc),
    .start(adc_start),
    .o_sclk(sclk_adc),
    .o_mosi(mosi_adc),
    .data(data_adc),
    .clk(clk),
    .o_cs(adc_cs),
    .init(adc_init)
  );
  
  always @(negedge clk) begin

    if (start_adc && !(busy_adc || is_init) && counter == 0) begin
      if (init) begin
        counter = 0;
        is_init = 1;
        adc_init = 1;
        //Start a 7 clock cycle delay
        delay = 7;
      end
      adc_start = 1;
    end
    //Special case when counter = 2: wait for PLL to lock first
    else if (counter == 3) begin
      delay = `PLL_WAIT;
      adc_start = 0;
      counter = 4;
    end
    else if (delay == 0 && is_init) begin
      

      
      //Wait for previous command to finish sending
      if (!busy_adc) begin
        //Stop initialization if we reach end of configuration sequence
        if (counter == `ADC_INIT_COUNT) is_init = 0;
        else begin
          //Load next data and start ADC
          data_adc_init = adc_conf[(conf_len - counter-1)*40 +: 40];
          adc_start = (counter != 2);
          delay = 7;
        end
        counter = counter + 1;
      end
    end  
    else if (delay == 1) begin
      //Reset init and start after delay
      adc_init = 0;
      adc_start = 0;
      delay = 0;
    end
    else begin
      adc_start = 0;
      if (delay > 0) delay = delay - 1; 
    end
  end
  
  always @(posedge clkmult) begin
    if (start_dac && !busy) begin
      sweep_count = SWEEP_START;
      dac_start = 1;
      reset_sweep = 0;
      diff = 3594873;
      diff2 = -32'H78B;
    end
    else if (dac_start && !reset_sweep) begin
      if(load_data_dac) begin
        if (sweep_count < SWEEP_STOP) begin
          sweep_count = sweep_count + diff; //not overflow safe
          diff = diff + diff2;
          diff2 = diff2 + 3;
        end
        else begin
          //Reset DAC back to starting value
          sweep_count = SWEEP_START;
          reset_sweep = 1;
        end
      end
    end
    else if (reset_sweep && load_data_dac) begin
      reset_sweep = 0;
      dac_start = 0;
      
    end
  end
endmodule
      

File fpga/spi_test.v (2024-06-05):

`ifdef SIMULATION

`define STARTUP_RESET_TIME 10

`else

`define STARTUP_RESET_TIME 262143

`endif

`define START_COMMAND 32'hf00dbabe
`define DELAY_TIME 2000

// Code your testbench here
// or browse Examples




module spi_test(
  input clk,
  input clkadc,
  input [7:0] adc_data,
  inout [7:0] io_usb,
  input rxf,
  input txe,
  input data_ready,
  output o_wr,
  output rd,
  output oe,
  output o_siwu,
  output mosi,
  output sclk,
  output cs,
  output lat,
  output o_conv_start,
  output o_adc_reset
  );

  wire lock;
  wire o_pll_reset;
  wire clkmult;

  reg start_adc = 0;
  reg start_dac = 0;
  wire spi_busy;
  reg [39:0] data = 0;
  reg init = 0 ;
  reg adc_en = 0;
  reg [19:0] delay_counter = 0;
  reg [11:0] delay_counter_2 = 0;

  reg[3:0] state = 0;
  reg [12:0] counter = 0;
  reg adc_reset = 0;
  wire [31:0] o_data_rd;
  reg wr = 0;
  wire wr_en;
  assign wr_en = wr ;
  reg start_read = 0;
  reg [6:0] debugCounter = 0;
  reg startup_done = 0;
  reg [4:0] siwu_counter = 0;
  reg pll_reset = 0;
  assign o_pll_reset = pll_reset;


  assign o_siwu = ~(siwu_counter > 1);
  wire usb_busy;
 
  assign o_adc_reset = adc_reset;
  reg [31:0] SWEEP_DIFF = 0;
  reg [31:0] SWEEP_START = 0;
  reg [31:0] SWEEP_STOP = 0;
  wire driver_cs;
  reg cs_enable = 0;
  assign cs = cs_enable && driver_cs;
  reg conv_start = 0;
  assign o_conv_start = conv_start;   

  wire data_valid;               
                                
  spi_test_pll spi_test_pll_inst(.REFERENCECLK(clkadc),
                               .PLLOUTCORE(),
                               .PLLOUTGLOBAL(clkmult),
                               .RESET(o_pll_reset),
                               .LOCK(lock));

  
  spi_driver DUT (
    .busy(spi_busy),
    .start_adc(start_adc),
    .start_dac(start_dac),
    .sclk(sclk),
    .mosi(mosi),
    .data(data),
    .clk(clk),
    .cs(driver_cs),
    .init (init),
    .data_valid(data_valid),
    .clkmult(clkmult),
    .SWEEP_DIFF(SWEEP_DIFF),
    .SWEEP_START(SWEEP_START),
    .SWEEP_STOP(SWEEP_STOP)
  );
 
  usb_int DUT2(
    .clkadc(clkadc),
    .clkusb(clk),
    .adc_data(adc_data),
    .io_usbdata(io_usb),
    .o_data_rd(o_data_rd) ,
    .rxf(rxf), //High = do not read
    .txe(txe), //High = do not write
    .o_wr(o_wr), //Low = write
    .rd(rd), //Low = read
    .oe(oe),
    .wr_en(wr_en),
    .start_read(start_read),
    .o_busy( usb_busy),
    .data_ready (data_valid)
  );  

                                   
  reg init_done = 0;
  assign lat = lock ;

  reg get_command = 0;  
  reg get_command_2 = 0;
  reg [4:0] offset = 0;
  reg init_done_2 = 0;
  reg [2:0] state2 = 0;
  reg data_ready_2 = 0;

  always @(negedge clk) begin
    
    if (!startup_done) begin
      //Initialize ADC by toggling reset pin and waiting for device to settle
      SWEEP_DIFF <= 3095815;
      SWEEP_START <= 1775837915;
      SWEEP_STOP <= 4291372423;
      cs_enable <= 1;
      conv_start <= (delay_counter > 1);
      if (delay_counter < `STARTUP_RESET_TIME ) begin
        adc_reset <= (delay_counter >= 1000);
        delay_counter <= delay_counter +1;
      end
      else startup_done <= 1;
    end
    else begin
      case(state)
        0: begin
          //State zero: Wait for data to get received at USB
          //When rxf goes high -> go to state 1
          delay_counter <= 0;
          if (!rxf) begin
            state <= 1;
            wr <= 0;
            start_read <= 1;
          end
        end
        1: begin
          //State 1: Read 4 bytes and compare to magic number
          //Success -> state 2
          if(!usb_busy && !start_read) begin
            if (o_data_rd != `START_COMMAND) state <= 0;
            else state <= 2;
          end
          else
            start_read <= 0;
        
        end
        2: begin
          //State 2: Begin ADC initialization
          start_adc <= 1;
          init <= 1;
          state <= 3;
          cs_enable <= 1;
        end
        3: begin
          //Wait for ADC initialization to finish
          if (!spi_busy && !start_adc) begin
            
            //Enable PLL
            pll_reset <= 1;
            if (lock) begin
              state <= 4;
              init_done <= 1;
              conv_start <= 0;
            end
          end
          else begin
            init <= 0;
            start_adc <= 0;
          end
        end
        
        4: begin
          get_command_2 <= get_command;
          if (get_command_2) begin
            if(siwu_counter == 0) begin
              siwu_counter <= 21;
            end
            else if (siwu_counter == 1) begin
              cs_enable <= 0;
              wr <= 0;
              if (!usb_busy && !rxf) begin
                start_read <= 1;
                state <= 5;
              end
            end
            else begin
              siwu_counter <= siwu_counter - 1;
            end
          end
          else begin
            wr <= 1;
            siwu_counter <= 0;
            cs_enable <= 1;
          end
        end
        5: begin
          start_read <= 0;
          if (!usb_busy) begin
            if (o_data_rd[31:30] == 1) begin
              cs_enable <= 1;
              start_adc <= 1;
              data <= {8'h02, 32'h3FFFFFFF & o_data_rd};
              state <= 6;
            end
            if (o_data_rd[31:30] == 2) begin
              case (o_data_rd[29:24])
                0: SWEEP_DIFF <= o_data_rd[15:0];
                1: SWEEP_START <= o_data_rd[15:0];
                2: SWEEP_STOP <= o_data_rd[15:0];
              endcase
            end
          end
        end
        6: begin
          start_adc <= 0;
          if(!spi_busy) begin
            state <= 4;
          end
        end
      endcase
    end
  end

                                   
                                 
  always @(posedge clkmult) begin
    init_done_2 <= init_done;
    data_ready_2 <= data_ready;
    if(init_done_2 && data_ready_2) begin
      case (state2)
        0: begin
          start_dac <= 1;
          state2 <= 1;
        end
        1: begin
          if (!spi_busy && !start_dac) begin
            state2 <= 2;
          end
          else
            start_dac <= 0;
        end
        2: begin
          if (delay_counter_2 == 0) begin
            delay_counter_2 <= `DELAY_TIME;
            get_command <= 1;
          end
          else if(delay_counter_2 == 1) begin
            if (offset == 0) begin
              state2 <= 0;
              delay_counter_2 <= 0;

            end
          end
          else if (delay_counter_2 < 700) begin
            get_command <= 0;
            delay_counter_2 <= delay_counter_2 - 1;
          end
          else begin
            delay_counter_2 <= delay_counter_2 - 1;
          end   
        end
      endcase
      offset <= offset + 1;
    end
  end
endmodule
